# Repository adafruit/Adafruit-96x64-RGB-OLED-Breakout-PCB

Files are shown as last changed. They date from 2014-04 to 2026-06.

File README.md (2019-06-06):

# PCB for the Adafruit Mini Color OLED breakout board

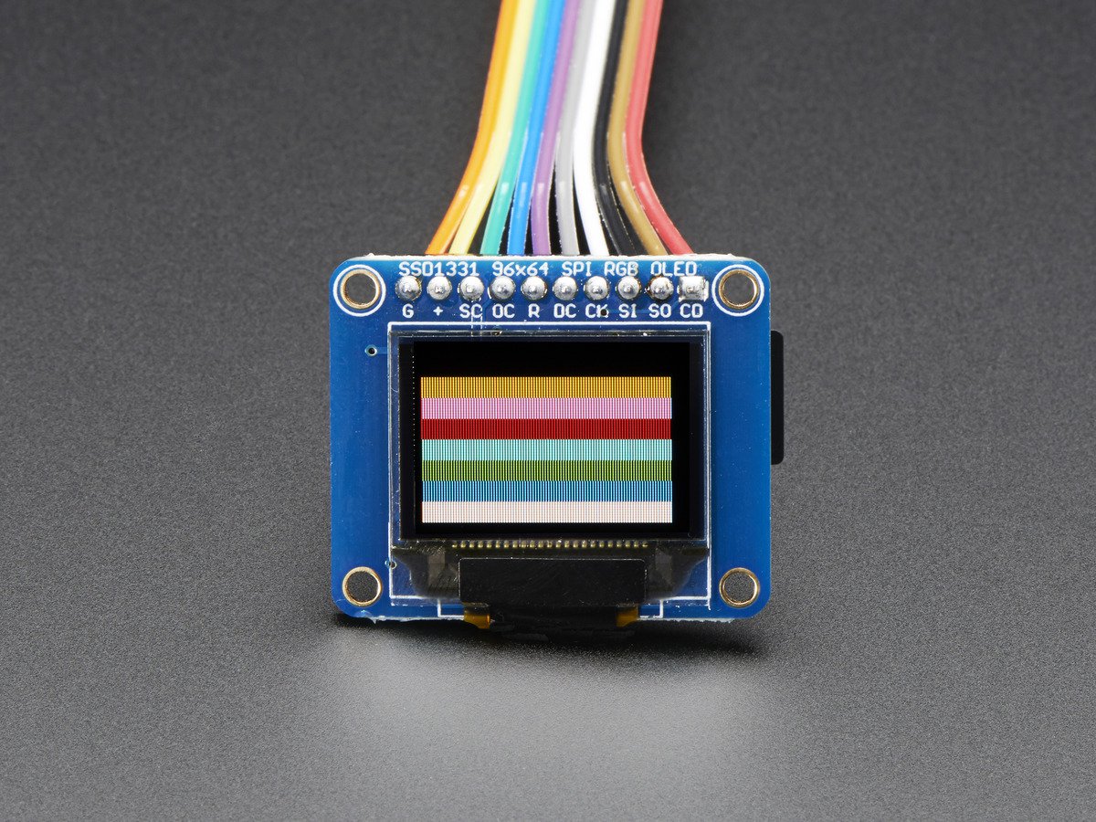
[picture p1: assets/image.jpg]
<a href="http://www.adafruit.com/products/684"><br/>Click here to purchase one from the Adafruit shop</a>

We love our black and white monochrome displays but we also like to dabble with some color now and then. Our new 0.96" color OLED displays are perfect when you need an ultra-small display with vivid, high-contrast 16-bit color. The visible portion of the OLED measures 0.96" diagonal and contains 96x64 RGB pixels, each one made of red, green and blue OLEDs. Each pixel can be set with 16-bits of resolution for a large range of colors. Because the display uses OLEDs, there is no backlight, and the contrast is very high (black is really black). We picked this display for its excellent color, this is the nicest mini OLED we could find!

This OLED uses the SSD1331 driver chip, which manages the display. You can talk to the driver chip using either 4-wire write-only SPI (clock, data, chip select, data/command and an optional reset pin). Included on the fully assembled breakout is the OLED display and a small boost converter (required for providing 12V to the OLED) and a microSD card holder. New! We've updated this design to have built-in logic level shifting so you can use it with 3-5VDC power and logic levels. Our example code shows how to read a bitmap from the uSD card and display it all via SPI.

Of course, we wouldn't just leave you with a datasheet and a "good luck!" - [ we've written a full open source graphics library that can draw pixels, lines, rectangles, circles, text and bitmaps as well as example code and a wiring tutorial](http://learn.adafruit.com/096-mini-color-oled).
The code is written for Arduino but can be easily ported to your favorite microcontroller!

OLED Breakout Board - 16-bit Color 0.96" w/microSD holder ([4:55](https://www.youtube.com/watch?feature=player_detailpage&v=Cvf2_pIx7Aw#t=295))

## License

Adafruit invests time and resources providing this open source design, 
please support Adafruit and open-source hardware by purchasing 
products from Adafruit!

Designed by Adafruit Industries.  
Creative Commons Attribution, Share-Alike license, check license.txt for more information
All text above must be included in any redistribution

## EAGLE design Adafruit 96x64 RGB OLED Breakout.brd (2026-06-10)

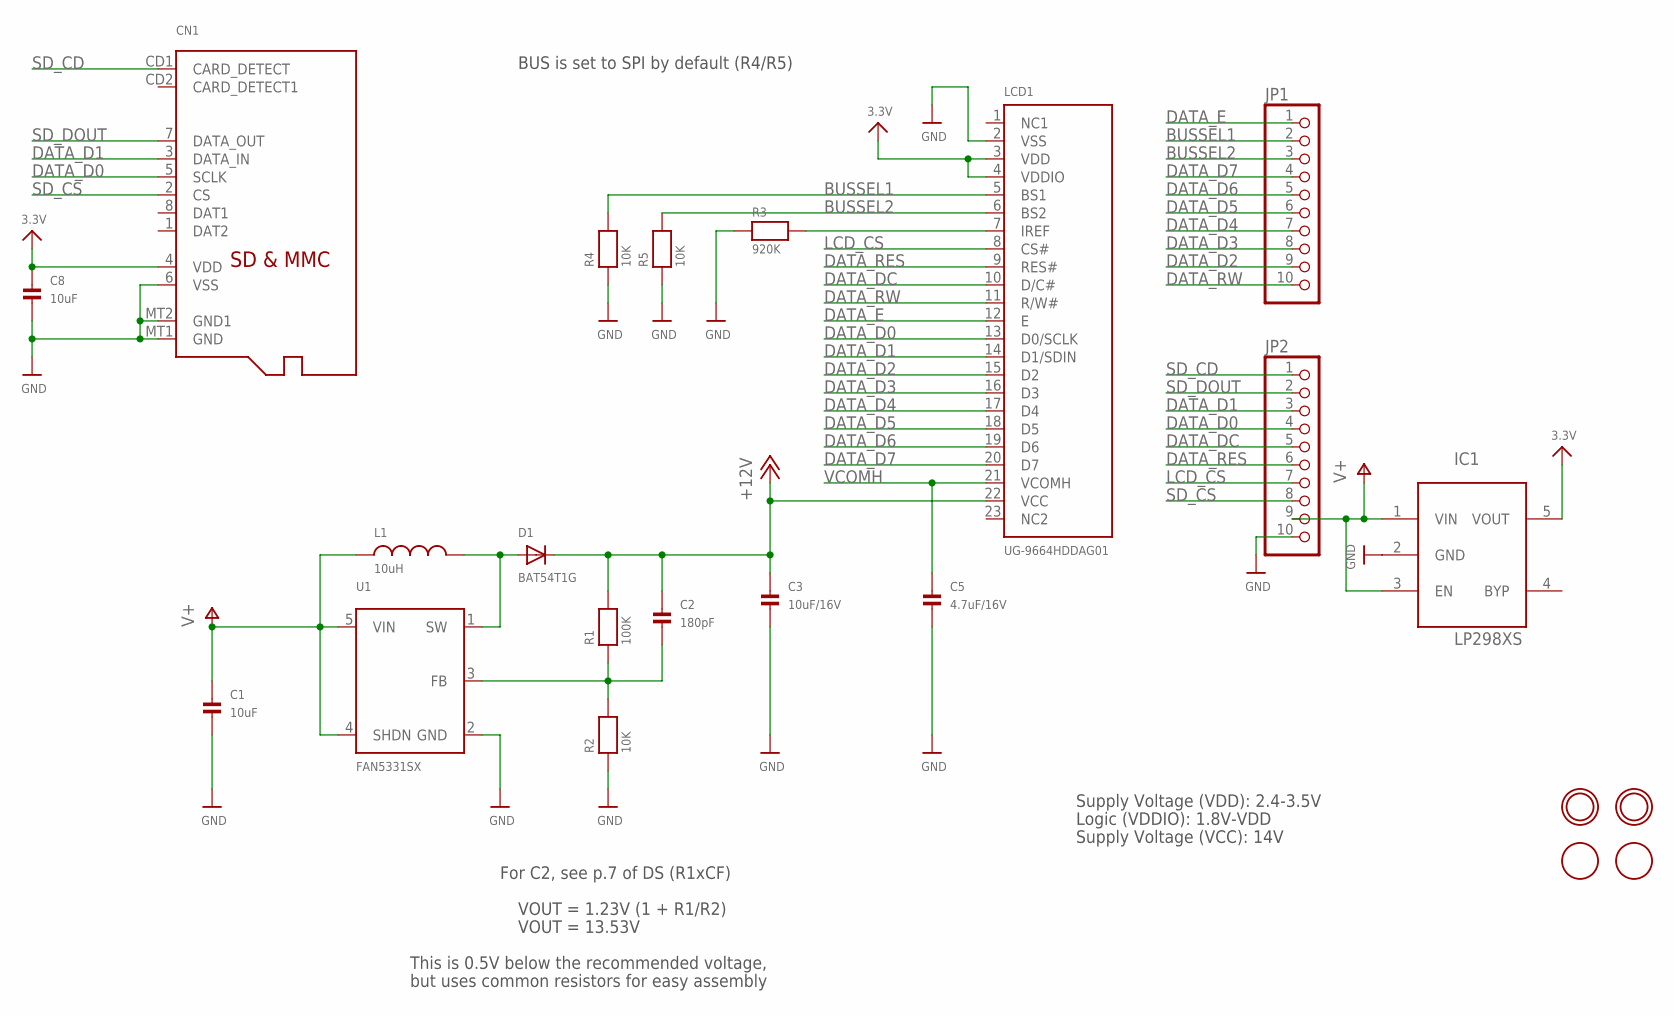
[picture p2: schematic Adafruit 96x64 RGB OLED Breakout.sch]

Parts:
C1, C8: 10uF; 0805
C2: 180pF; 0805
C3: 10uF/16V; 0805
C5: 4.7uF/16V; 0805
CN1: MICROSD
D1: BAT54T1G; SOD-123
IC1: LP298XS; SOT23-5L
JP1, JP2: HEADER-1X10THICKER; 1X10_ROUND_76
L1: 10uH; INDUCTOR_1007
LCD1: UG-9664HDDAG01; UG-9664HDDAG01_WRAPAROUND
R1: 100K; 0805
R2, R4, R5: 10K; 0805
R3: 920K; 0805
U1: FAN5331SX; SOT23-5
U$9, U$11: MOUNTINGHOLE2.0; MOUNTINGHOLE_2.0_PLATED
U$12, U$13: FIDUCIAL; FIDUCIAL_1MM

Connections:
3.3V: C8.1, CN1.4 (VDD), IC1.5 (VOUT), LCD1.3 (VDD), LCD1.4 (VDDIO)
+12V: C2.1, C3.1, D1.C, LCD1.22 (VCC), R1.2
BUSSEL1: JP1.2, LCD1.5 (BS1), R4.2
BUSSEL2: JP1.3, LCD1.6 (BS2), R5.2
DATA_D0: CN1.5 (SCLK), JP2.4, LCD1.13 (D0/SCLK)
DATA_D1: CN1.3 (DATA_IN), JP2.3, LCD1.14 (D1/SDIN)
DATA_D2: JP1.9, LCD1.15 (D2)
DATA_D3: JP1.8, LCD1.16 (D3)
DATA_D4: JP1.7, LCD1.17 (D4)
DATA_D5: JP1.6, LCD1.18 (D5)
DATA_D6: JP1.5, LCD1.19 (D6)
DATA_D7: JP1.4, LCD1.20 (D7)
DATA_DC: JP2.5, LCD1.10 (D/C#)
DATA_E: JP1.1, LCD1.12 (E)
DATA_RES: JP2.6, LCD1.9 (RES#)
DATA_RW: JP1.10, LCD1.11 (R/W#)
GND: C1.2, C3.2, C5.2, C8.2, CN1.6 (VSS), CN1.MT1 (GND), CN1.MT2 (GND1), IC1.2 (GND), JP2.10, LCD1.2 (VSS), R2.1, R3.1, R4.1, R5.1, U1.2 (GND)
LCD_CS: JP2.7, LCD1.8 (CS#)
unnamed: D1.A, L1.P$2 (2), U1.1 (SW)
unnamed: C2.2, R1.1, R2.2, U1.3 (FB)
unnamed: LCD1.7 (IREF), R3.2
SD_CD: CN1.CD1 (CARD_DETECT), JP2.1
SD_CS: CN1.2 (CS), JP2.8
SD_DOUT: CN1.7 (DATA_OUT), JP2.2
V+: C1.1, IC1.1 (VIN), IC1.3 (EN), JP2.9, L1.P$1 (1), U1.4 (SHDN), U1.5 (VIN)
VCOMH: C5.1, LCD1.21 (VCOMH)

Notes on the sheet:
Supply Voltage (VDD): 2.4-3.5V
Logic (VDDIO): 1.8V-VDD
Supply Voltage (VCC): 14V
For C2, see p.7 of DS (R1xCF)
VOUT = 1.23V (1 + R1/R2)
VOUT = 13.53V
This is 0.5V below the recommended voltage,
but uses common resistors for easy assembly
BUS is set to SPI by default (R4/R5)

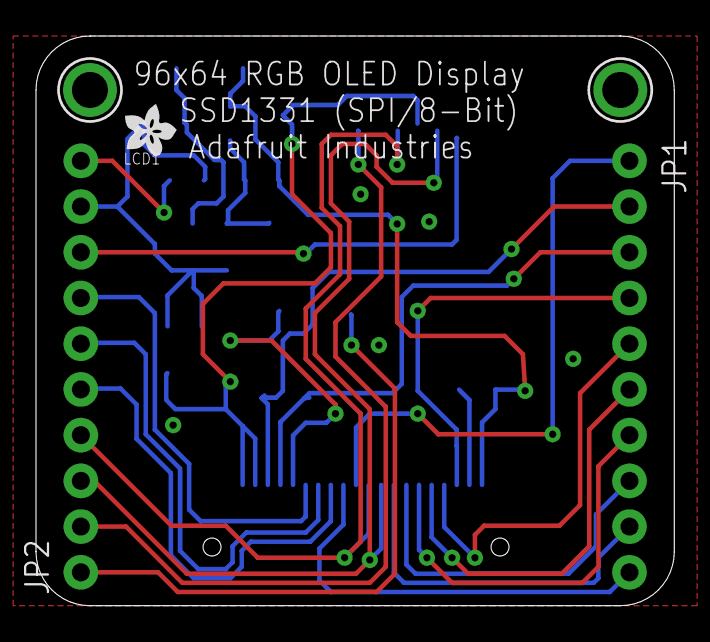
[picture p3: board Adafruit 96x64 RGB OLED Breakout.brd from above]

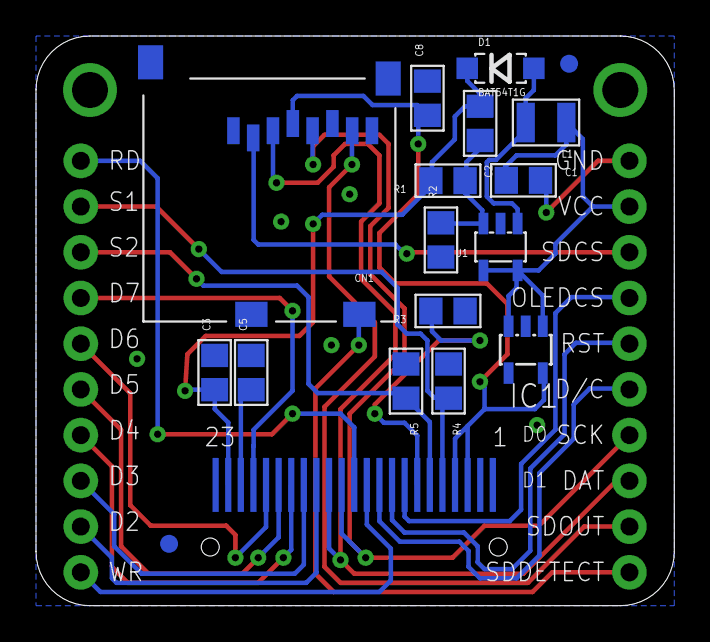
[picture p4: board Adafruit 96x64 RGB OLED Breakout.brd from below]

Board: 2 copper layers, 35.5 x 31.6 mm, 23 parts (17 on the bottom side), 26 nets.

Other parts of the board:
U$22: ADAFRUIT200MIL

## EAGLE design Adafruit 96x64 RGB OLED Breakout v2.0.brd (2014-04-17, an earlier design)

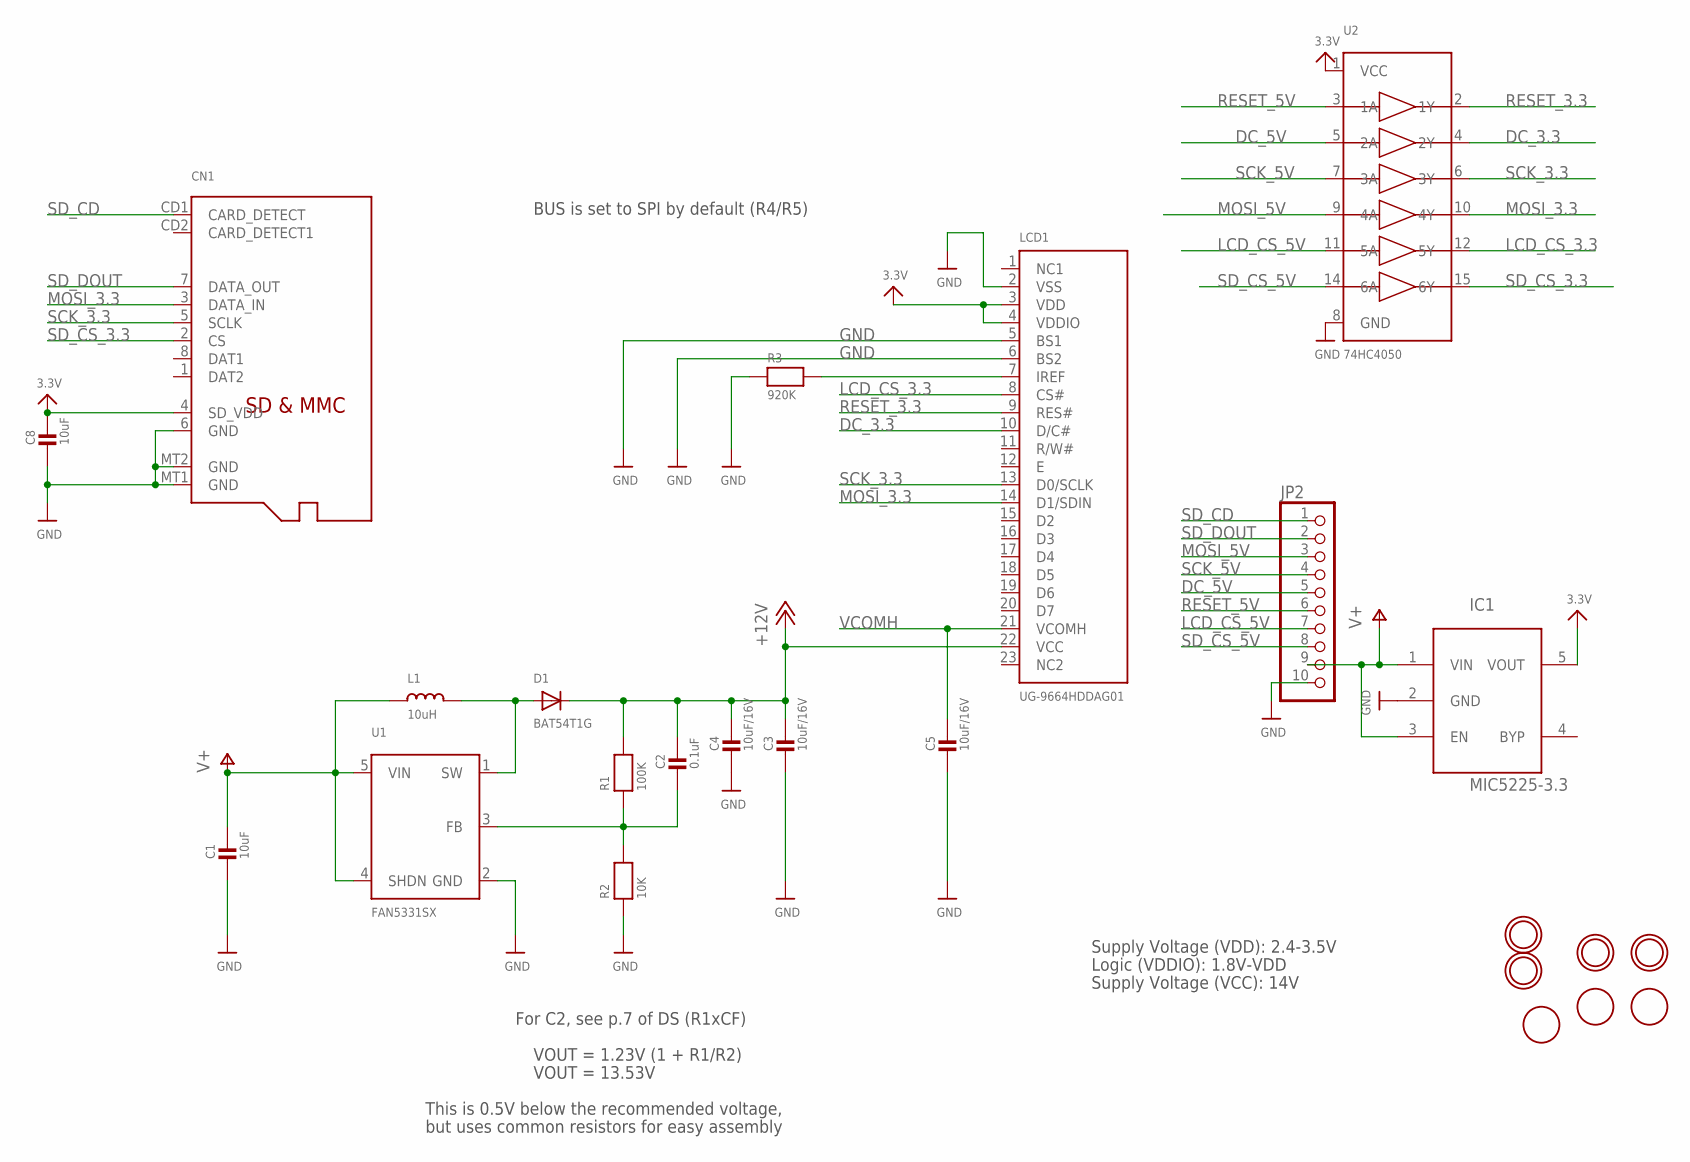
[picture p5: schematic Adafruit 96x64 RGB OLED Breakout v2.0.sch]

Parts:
C1, C8: 10uF; 0805
C2: 0.1uF; 0805
C3, C4, C5: 10uF/16V; 0805
CN1: MICROSD
D1: BAT54T1G; SOD-123
IC1: MIC5225-3.3; SOT23-5L
JP2: HEADER-1X10THICKER; 1X10_ROUND_76
L1: 10uH; INDUCTOR_1007
LCD1: UG-9664HDDAG01; UG-9664HDDAG01_WRAPAROUND
R1: 100K; 0805
R2: 10K; 0805
R3: 920K; 0805
U1: FAN5331SX; SOT23-5
U2: 74HC4050; SOIC16
U$9, U$10, U$11, U$15: MOUNTINGHOLE2.5; MOUNTINGHOLE_2.5_PLATED
U$12, U$13, U$16: FIDUCIAL; FIDUCIAL_1MM

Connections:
3.3V: C8.1, CN1.4 (SD_VDD), IC1.5 (VOUT), LCD1.3 (VDD), LCD1.4 (VDDIO), U2.1 (VCC)
+12V: C2.1, C3.1, C4.1, D1.C, LCD1.22 (VCC), R1.2
DC_3.3: LCD1.10 (D/C#), U2.4 (2Y)
DC_5V: JP2.5, U2.5 (2A)
GND: C1.2, C3.2, C4.2, C5.2, C8.2, CN1.6 (GND), CN1.MT1 (GND), CN1.MT2 (GND), IC1.2 (GND), JP2.10, LCD1.2 (VSS), LCD1.5 (BS1), LCD1.6 (BS2), R2.1, R3.1, U1.2 (GND), U2.8 (GND)
LCD_CS_3.3: LCD1.8 (CS#), U2.12 (5Y)
LCD_CS_5V: JP2.7, U2.11 (5A)
MOSI_3.3: CN1.3 (DATA_IN), LCD1.14 (D1/SDIN), U2.10 (4Y)
MOSI_5V: JP2.3, U2.9 (4A)
unnamed: D1.A, L1.P$2 (2), U1.1 (SW)
unnamed: C2.2, R1.1, R2.2, U1.3 (FB)
unnamed: LCD1.7 (IREF), R3.2
RESET_3.3: LCD1.9 (RES#), U2.2 (1Y)
RESET_5V: JP2.6, U2.3 (1A)
SCK_3.3: CN1.5 (SCLK), LCD1.13 (D0/SCLK), U2.6 (3Y)
SCK_5V: JP2.4, U2.7 (3A)
SD_CD: CN1.CD1 (CARD_DETECT), JP2.1
SD_CS_3.3: CN1.2 (CS), U2.15 (6Y)
SD_CS_5V: JP2.8, U2.14 (6A)
SD_DOUT: CN1.7 (DATA_OUT), JP2.2
V+: C1.1, IC1.1 (VIN), IC1.3 (EN), JP2.9, L1.P$1 (1), U1.4 (SHDN), U1.5 (VIN)
VCOMH: C5.1, LCD1.21 (VCOMH)

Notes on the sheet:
Supply Voltage (VDD): 2.4-3.5V
Logic (VDDIO): 1.8V-VDD
Supply Voltage (VCC): 14V
For C2, see p.7 of DS (R1xCF)
VOUT = 1.23V (1 + R1/R2)
VOUT = 13.53V
This is 0.5V below the recommended voltage,
but uses common resistors for easy assembly
BUS is set to SPI by default (R4/R5)

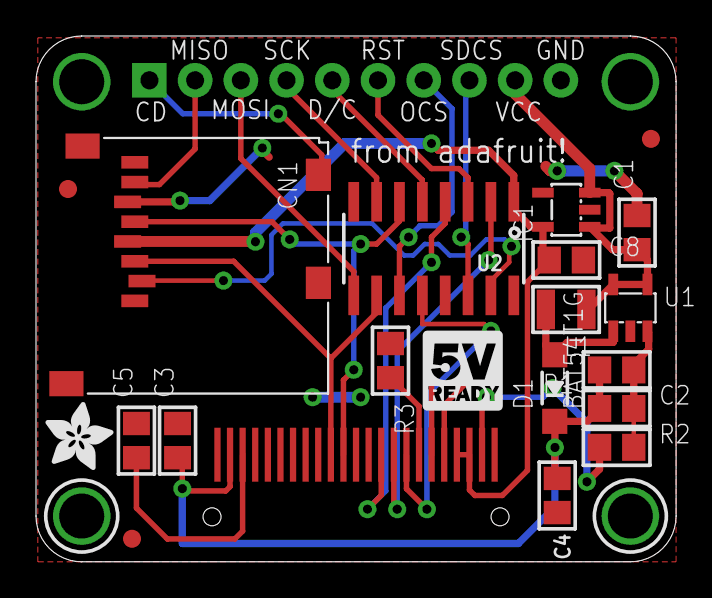
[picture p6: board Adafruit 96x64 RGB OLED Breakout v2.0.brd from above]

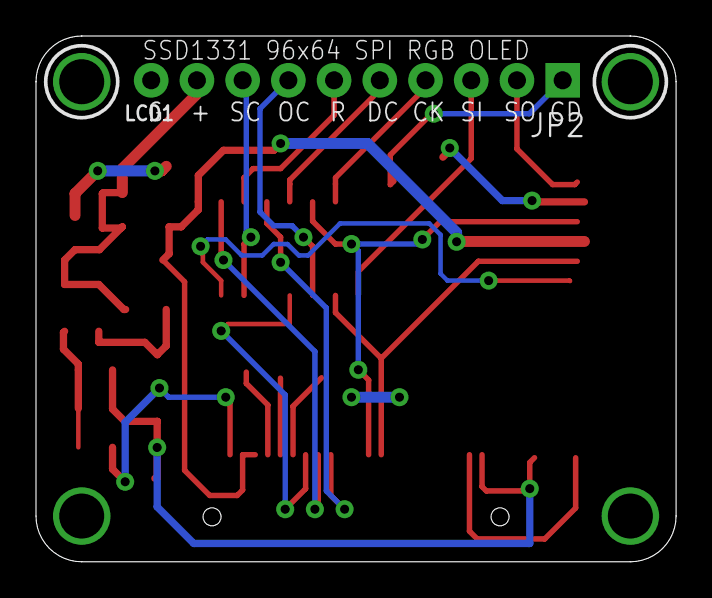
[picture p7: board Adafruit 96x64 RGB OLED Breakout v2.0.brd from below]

Board: 2 copper layers, 35.6 x 29.2 mm, 26 parts (4 on the bottom side), 22 nets.

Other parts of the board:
U$17: ADAFRUIT_3.5MM
U$28: LOGIC_5VREADY_5MM

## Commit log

2012-03-08 v0.3 with fixed S1/S2 silkscreen
    [Adafruit 96x64 RGB OLED Breakout.brd, Adafruit 96x64 RGB OLED Breakout.sch]
2014-04-17 v2 (SPI only)
    [Adafruit 96x64 RGB OLED Breakout v2.0.brd, Adafruit 96x64 RGB OLED Breakout v2.0.sch]
2026-06-03 update file format to XML
    [Adafruit 96x64 RGB OLED Breakout.brd, Adafruit 96x64 RGB OLED Breakout.sch]
